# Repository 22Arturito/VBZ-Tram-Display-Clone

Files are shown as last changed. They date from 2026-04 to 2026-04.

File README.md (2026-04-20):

# VBZ Tram Display Clone

A homemade replica of the Zürich VBZ tram departure board. Shows real-time departure data for any tram, bus, or train station in Switzerland on three chained HUB75 LED matrix panels.






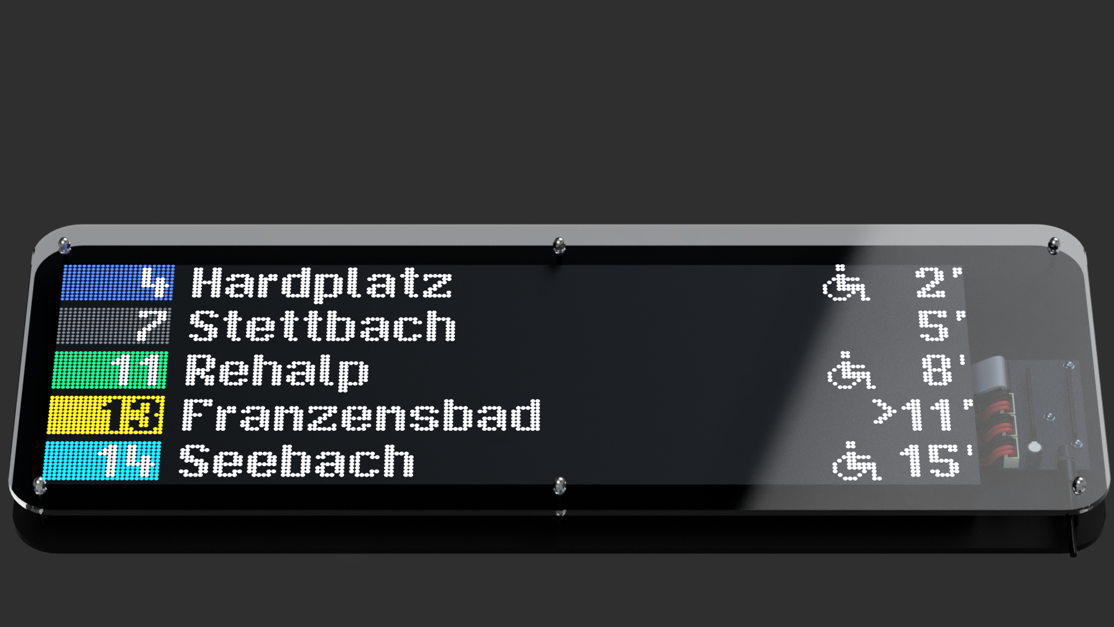
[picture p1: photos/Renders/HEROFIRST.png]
VBZ Tram Display


> Based on the original work by [sschueller](https://github.com/sschueller/vbz-fahrgastinformation).

---

## Table of Contents

- [Background](#background)
- [Features](#features)
- [Gallery](#gallery)
- [Build Your Own](#build-your-own)
- [Hardware](#hardware)
- [Wiring](#wiring)
- [Software Setup](#software-setup)
- [OTA Updates](#ota-updates)
- [Web Interface](#web-interface)
- [Physical Button](#physical-button)
- [Night Mode](#night-mode)
- [Troubleshooting](#troubleshooting)
- [Project Structure](#project-structure)
- [Contributors](#contributors)
- [Credits](#credits)

---

## Background

This project started with [sschueller's vbz-fahrgastinformation](https://github.com/sschueller/vbz-fahrgastinformation), a faithful recreation of the actual VBZ passenger information system, complete with the real font, real line colors, and real-time data from the Swiss open transport API. Pretty much everything technical in here traces back to his work — the firmware, the font and bitmap data, the HUB75 panel setup, the data pipeline. The things I added (web UI, clock screensaver with weather, night mode, OTA updates) are built on top of that. Big credit to him especially for the bitmap font work, which is the most distinctive visual part of the whole thing.

His original build used a single 64×128 panel. I switched to three chained 64×64 panels, which is close to what his newer products do and gives more flexibility when sourcing. The case design is heavily inspired by his finished [StationDisplay](https://www.stationdisplay.com) product. In many ways I wanted exactly what he sells, just as something I could build myself.

If you don't have the time or interest to build your own, I'd strongly recommend just buying from him directly at [stationdisplay.com](https://www.stationdisplay.com). It's an extraordinary Swiss-made product with proper support behind it.

This DIY version comes in at around CHF 80–120, which makes it accessible to a lot more people. That said, it is a DIY build. The finish, the support, and the overall quality of the bought version are on a different level. You get what you pay for.

A few things I contributed on top of his work:

- **Three 64×64 panels** chained to 192×64px total, instead of a single 64×128 panel
- **Custom PCB** for a clean, repeatable build
- **Laser-cut MDF and acrylic enclosure** closely inspired by his commercial StationDisplay
- **Web UI** for live configuration and station search
- **Clock screensaver** with date, live weather, UV index, and rain forecast
- **Night mode** with automatic scheduling and manual override
- **OTA firmware updates** over WiFi

---

## Features

- Live departure data from [opentransportdata.swiss](https://opentransportdata.swiss), falls back to scheduled if unavailable
- Two configurable stations, switchable via button or web interface
- Direction filter: both / outbound / inbound, persisted to flash
- VBZ tram line colors for all known Zürich lines
- Accessibility indicator for low-floor vehicles
- Live vs. scheduled marker, late departure indicator
- Night mode with amber colors and low brightness, auto-scheduled (22:00–06:00) with manual override
- Clock screensaver with date and live weather via [Open-Meteo](https://open-meteo.com), no API key needed
- Web configuration UI with live departure view and station search
- OTA firmware updates over WiFi

---

## Gallery

| | |
|---|---|
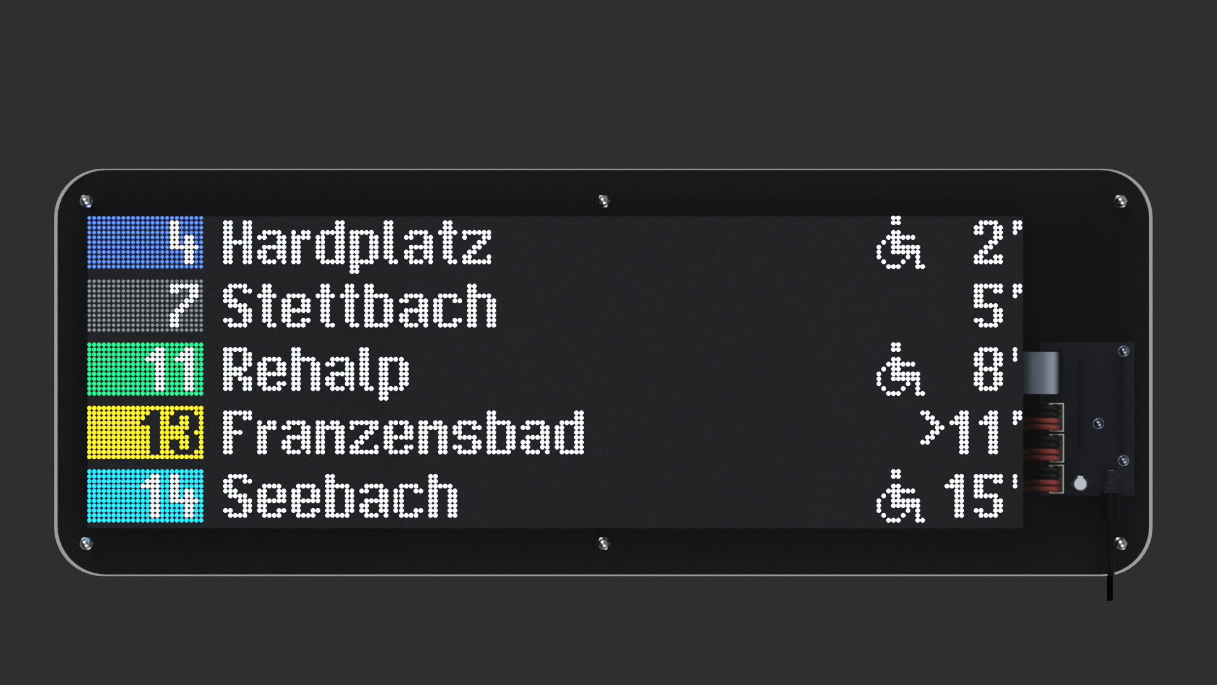
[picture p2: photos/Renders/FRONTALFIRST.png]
Front
| Hero |  |
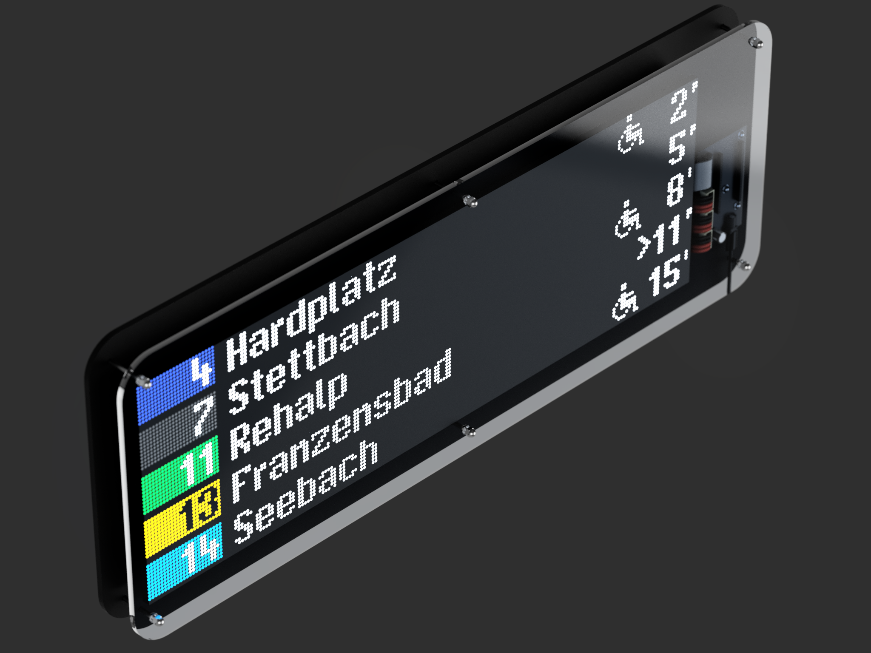
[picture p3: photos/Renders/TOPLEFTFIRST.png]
Top Left
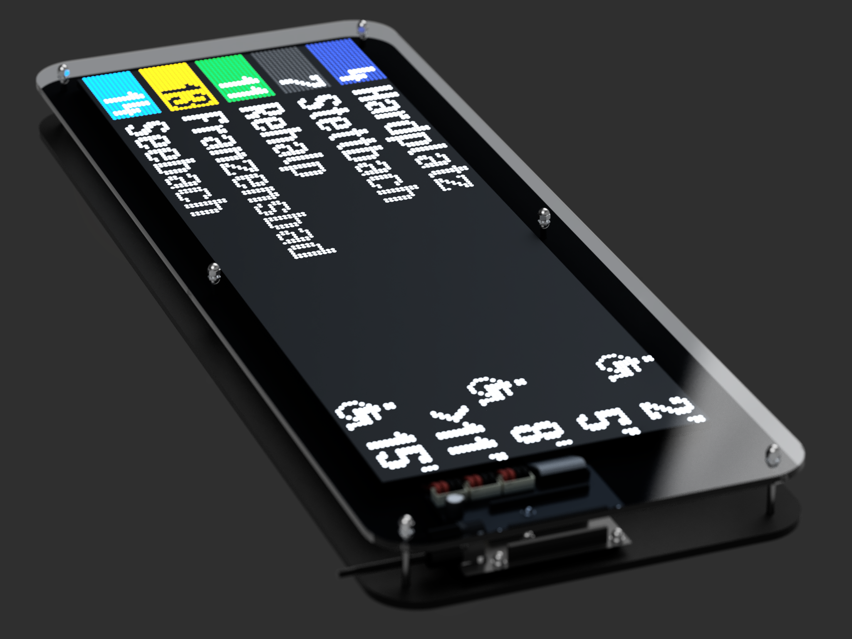
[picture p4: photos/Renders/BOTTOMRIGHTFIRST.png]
Bottom Right
|  |  |

---

## Build Your Own

Total cost is roughly **CHF 80–120** depending on where you source parts.

| Component | Source | Approx. Cost |
|---|---|---|
| 3× P3 64×64 HUB75E LED panels | AliExpress | CHF 45–60 |
| Freenove ESP32-S3 WROOM | AliExpress / Amazon | CHF 12–18 |
| Custom PCB (5 pcs min) | JLCPCB / PCBWay | CHF 8–12 |
| PCB components (caps, resistors, connectors) | LCSC / Mouser | CHF 5–10 |
| 5V 3A power supply | AliExpress | CHF 5–8 |
| 3× HUB75E ribbon cables (2×8 IDC) | AliExpress | CHF 4–6 |
| Acrylic sheet 600×200mm 5mm | Local laser shop | CHF 5–10 |
| MDF sheet 600×200mm 5mm | Local laser shop | CHF 3–5 |
| M4 hardware (bolts + nuts) | Hardware store | CHF 3–5 |

> Panels are the biggest variable in price and fluctuate on AliExpress. Search **"64x64 P3 HUB75E RGB LED matrix"**.

### Steps

1. **Order parts.** Use the BOM in `hardware/pcb/` for exact PCB components. Order panels, ESP32, and cables from AliExpress at the same time to save on shipping.

2. **Get the PCB made.** Upload the Gerber zip from `hardware/pcb/` to [JLCPCB](https://jlcpcb.com) or [PCBWay](https://pcbway.com). Standard 2-layer, 1.6mm, any colour. Minimum order is 5 pcs for ~$2.

3. **Laser-cut the frame.** Send the DXF files in `hardware/3d/` to a local laser cutting service or makerspace. 5mm MDF for the frame (paint it black), 5mm clear acrylic for the front panel.

4. **Solder the PCB.** Solder all SMD components first, then connectors. The schematic and assembly drawing are in `hardware/pcb/`.

5. **Assemble.** Chain the three LED panels together with ribbon cables. Connect power wires to each panel. Mount panels into the MDF frame using M4 bolts and nuts, then attach the acrylic front.

6. **Flash and configure.** Follow [Software Setup](#software-setup) below. First flash is via USB; all updates after that are OTA over WiFi.

---

## Hardware

| Component | Qty | Details |
|---|---|---|
| LED Matrix Panels | 3 | 64×64px P3 HUB75E, chained (192×64px total) |
| Microcontroller | 1 | Freenove ESP32-S3 WROOM (8MB Flash / 8MB PSRAM) |
| Custom PCB | 1 | See `hardware/pcb/` for schematics and BOM |
| Power Supply | 1 | 5V 3A DC barrel jack |
| HUB75E Ribbon Cables | 3 | 2×8 IDC, panel-to-panel and panel-to-PCB |
| JST Power Wires | 3 | Custom length, custom terminated |
| Acrylic sheet | 1 | 600×200mm, 5mm, laser-cut front panel |
| MDF sheet | 1 | 600×200mm, 5mm, laser-cut frame, painted black |
| M4 bolt 60mm | 6 | Frame assembly |
| M4 bolt 40mm | 12 | Frame assembly |
| M4 knurl nut | 9 | Frame assembly |
| M4 square nut | 12 | Frame assembly |

Laser-cut files are in `hardware/3d/`. PCB schematics and Gerber files are in `hardware/pcb/`.

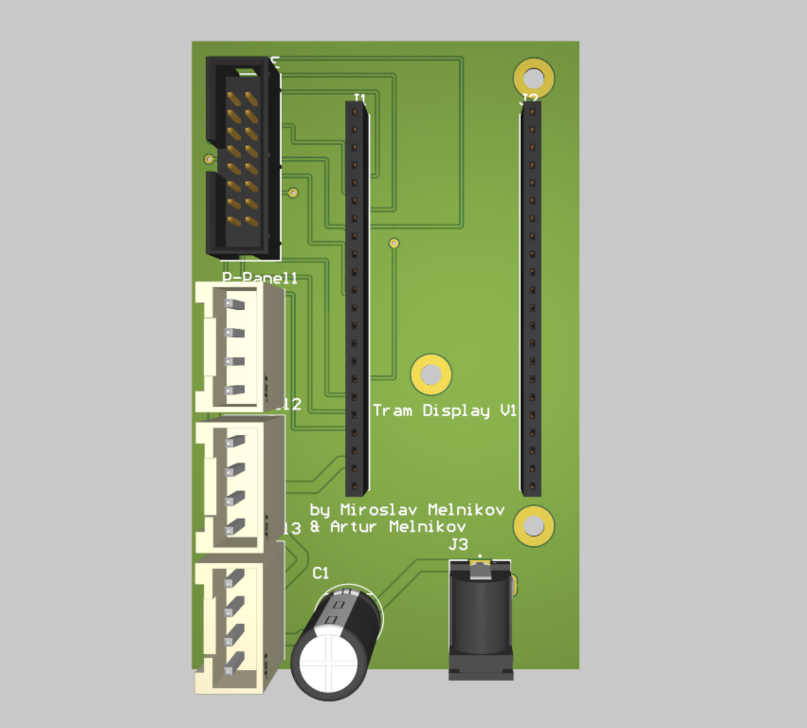
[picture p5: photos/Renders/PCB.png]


---

## Wiring

The custom PCB handles the connection between the ESP32-S3 and the HUB75E panels.

| HUB75E Pin | ESP32-S3 GPIO |
|---|---|
| R1 | 4 |
| G1 | 5 |
| B1 | 6 |
| R2 | 7 |
| G2 | 15 |
| B2 | 16 |
| A | 17 |
| B | 18 |
| C | 8 |
| D | 14 |
| E | 10 |
| LAT | 11 |
| OE | 12 |
| CLK | 13 |

> Double-check against your `Config.h` as pin assignments can vary.

---

## Software Setup

### 1. Configure `firmware/include/Config.h`

Copy the template and fill in your details:

```bash
cp firmware/include/Config.h.dist firmware/include/Config.h
```

```cpp
#define OPEN_DATA_API_KEY "your_key_here"  // from opentransportdata.swiss
#define WEATHER_LAT "47.37"                // your latitude
#define WEATHER_LON "8.54"                 // your longitude
#define BRIGHTNESS_FIXED 80               // 0–255, or -1 for ambient sensor
```

Get a free API key at [opentransportdata.swiss](https://opentransportdata.swiss).
Find station BPUIC IDs in the xlsx at [bav_liste](https://opentransportdata.swiss/de/dataset/bav_liste).

### 2. Flash via USB

Open the `firmware/` folder in PlatformIO and flash:

```bash
pio run -e freenove_esp32_s3_wroom -t upload
```

### 3. Connect to WiFi

On first boot the display shows **"connect to: vbz-anzeige"**. Connect to that network (password: `123456`), open a browser and the captive portal opens automatically. Enter your home WiFi credentials and save.

### 4. Configure stations

After connecting, the display shows its IP. Open `http://<IP>/config` to set your stations, night hours, and brightness.

---

## OTA Updates

After the first USB flash, all future updates can be done wirelessly.

Set the device IP in `firmware/platformio.ini`:

```ini
upload_port = 192.168.1.xx
```

Then upload:

```bash
pio run -e ota -t upload
```

OTA password: `vbz1234` (configurable in `main.cpp`).

---

## Web Interface

Open `http://<IP>/config` in any browser on the same network.

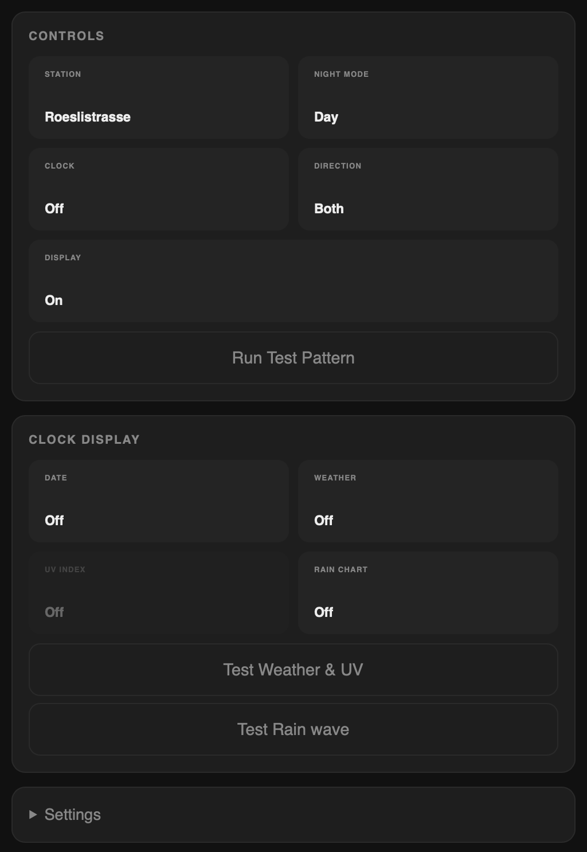
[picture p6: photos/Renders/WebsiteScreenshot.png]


| Button | Action |
|---|---|
| Switch Station | Toggle between Station 1 and Station 2 |
| Switch to Night / Day | Toggle night mode manually |
| Dir: Both / H / R | Cycle direction filter |
| Turn Off / On | Toggle display on/off |
| Clock: Off / On | Toggle clock screensaver |
| Test Display | Flash red/green/blue/white to verify panels |

Station search lets you look up a stop by name and fills the BPUIC ID automatically.

---

## Physical Button

| Press | Action |
|---|---|
| Single press | Switch between Station 1 and Station 2 |
| Double press | Toggle night mode |
| Long press (>800ms) | Toggle display off/on |

---

## Night Mode

Activates automatically between configured hours (default 22:00–06:00). All colors switch to amber and brightness drops to ~10%. Can be overridden manually via button or web interface and the override clears at the next scheduled boundary.

---

## Troubleshooting

**Display shows garbage / random pixels**
Check ribbon cable orientation. HUB75E cables are not keyed, try flipping the connector on the first panel.

**Only the first panel lights up**
The chain order matters. Panel 1 connects to the PCB, panel 2 connects to panel 1's output, panel 3 to panel 2's output.

**No departures shown, just dashes**
Your API key is missing or wrong. Double-check `Config.h` and make sure you have a valid key from [opentransportdata.swiss](https://opentransportdata.swiss).

**OTA upload fails**
Make sure the device is on the same network and the IP in `platformio.ini` is correct. The OTA password is `vbz1234`.

**Display flickers or shows noise**
Lower `BRIGHTNESS_FIXED` in `Config.h`. Some panels need `latch_blanking` tuned, see the comments in `Display.cpp`.

**WiFi captive portal doesn't open**
Navigate manually to `192.168.4.1` in your browser after connecting to the `vbz-anzeige` hotspot.

---

## Project Structure

```
firmware/           ESP32 PlatformIO project
hardware/
  pcb/              Schematic, Gerber files, BOM
  3d/               Laser-cut DXF files for MDF frame and acrylic panel
photos/             Build photos and renders
generate_texture.py Generates a P3 LED texture for renders
```

---

## Contributors

**Artur Melnikov** — firmware, PCB, enclosure design, renders

**Miroslav Melnikov** — recreated the LED display panels in CAD, display testing, and a genuine interest in the project that kept it moving

**Bhavya Sharma** — helped with soldering and assembling the physical display

---

## Credits

Built on top of [sschueller's vbz-fahrgastinformation](https://github.com/sschueller/vbz-fahrgastinformation), used under MIT license. The original concept, font, and data pipeline approach all originate from his work. This project wouldn't exist without it.

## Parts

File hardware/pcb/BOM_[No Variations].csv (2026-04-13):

Name | Description | Designator | Part Number | Price | Qty
EEUTA1A102 | Aluminum Electrolytic Capacitors (Radial Lead Type) AEC-Q200 Qualified 1000uF ±20% 10V | C1 | Panasonic EEUTA1A102 |  | 1
61201621621 | WR-BHD Straight Male, Box Header, Through Hole, 2 Rows, 16 Contacts, 2.54mm Pitch | HUB75E | Wurth Elektronik 61201621621 | 0.60978 | 1
61302211821 | Btb Conn, Rcpt, 22Pos, 1Row, 2.54Mm Rohs Compliant: Yes | J1, J2 | Wurth Elektronik 61302211821, | 9.58055 | 2
PJ-102A | PJ-102A 2.0 x 6.5 mm, 2.5 A, Horizontal, Through Hole, Tapered Pins, Dc Power Jack Connector | J3 | Same Sky PJ-102A | 0.3306 | 1
BH4P-VH-1(LF)(SN) | VH Series 4 Position 3.96 mm Pitch Through Hole Shrouded Header | P_Panel3, P-Panel1, P-Panel2 | JST BH4P-VH-1(LF)(SN), | 0.7965 | 3

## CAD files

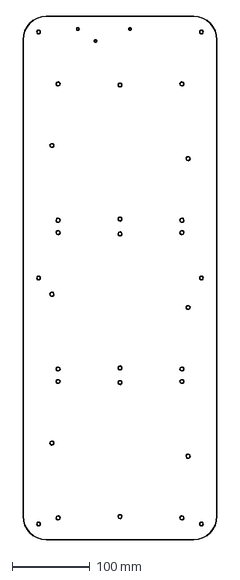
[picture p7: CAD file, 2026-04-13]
hardware/3d/Lasercutter Files/MDF BasePlate .dxf
250.0 x 675.0 mm

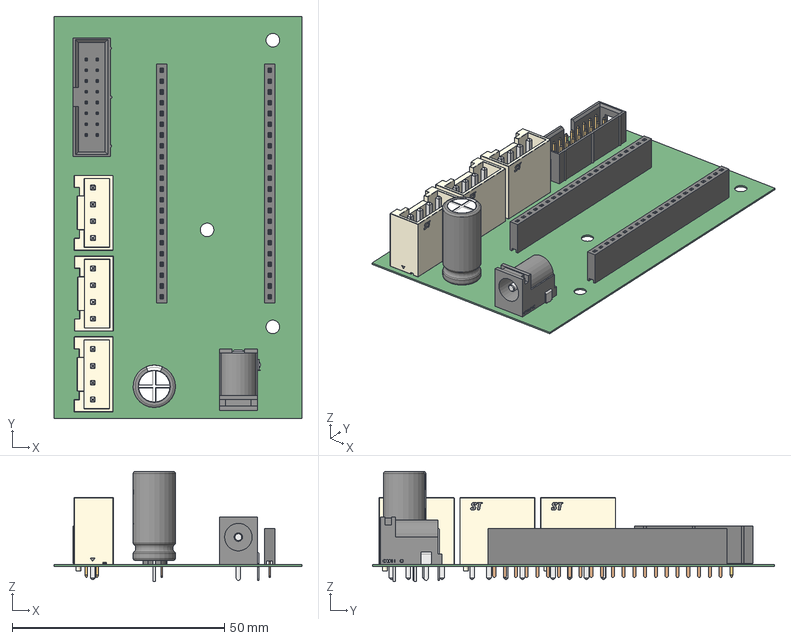
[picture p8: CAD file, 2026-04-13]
hardware/pcb/STEP_[No Variations] for PCB1.PcbDoc.step
58.4 x 94.7 x 26.0 mm
Pins x 3
Pin1_Triangle x 3
JST x 3
logo x 2
6130xx11821_PIN x 44
6120xx21621_PIN x 16
marking
bottom
polarity marking
top
terminal

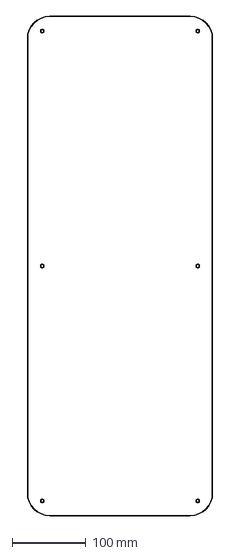
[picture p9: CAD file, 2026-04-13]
hardware/3d/Lasercutter Files/AcrylicFrontPlate.dxf
250.0 x 675.0 mm

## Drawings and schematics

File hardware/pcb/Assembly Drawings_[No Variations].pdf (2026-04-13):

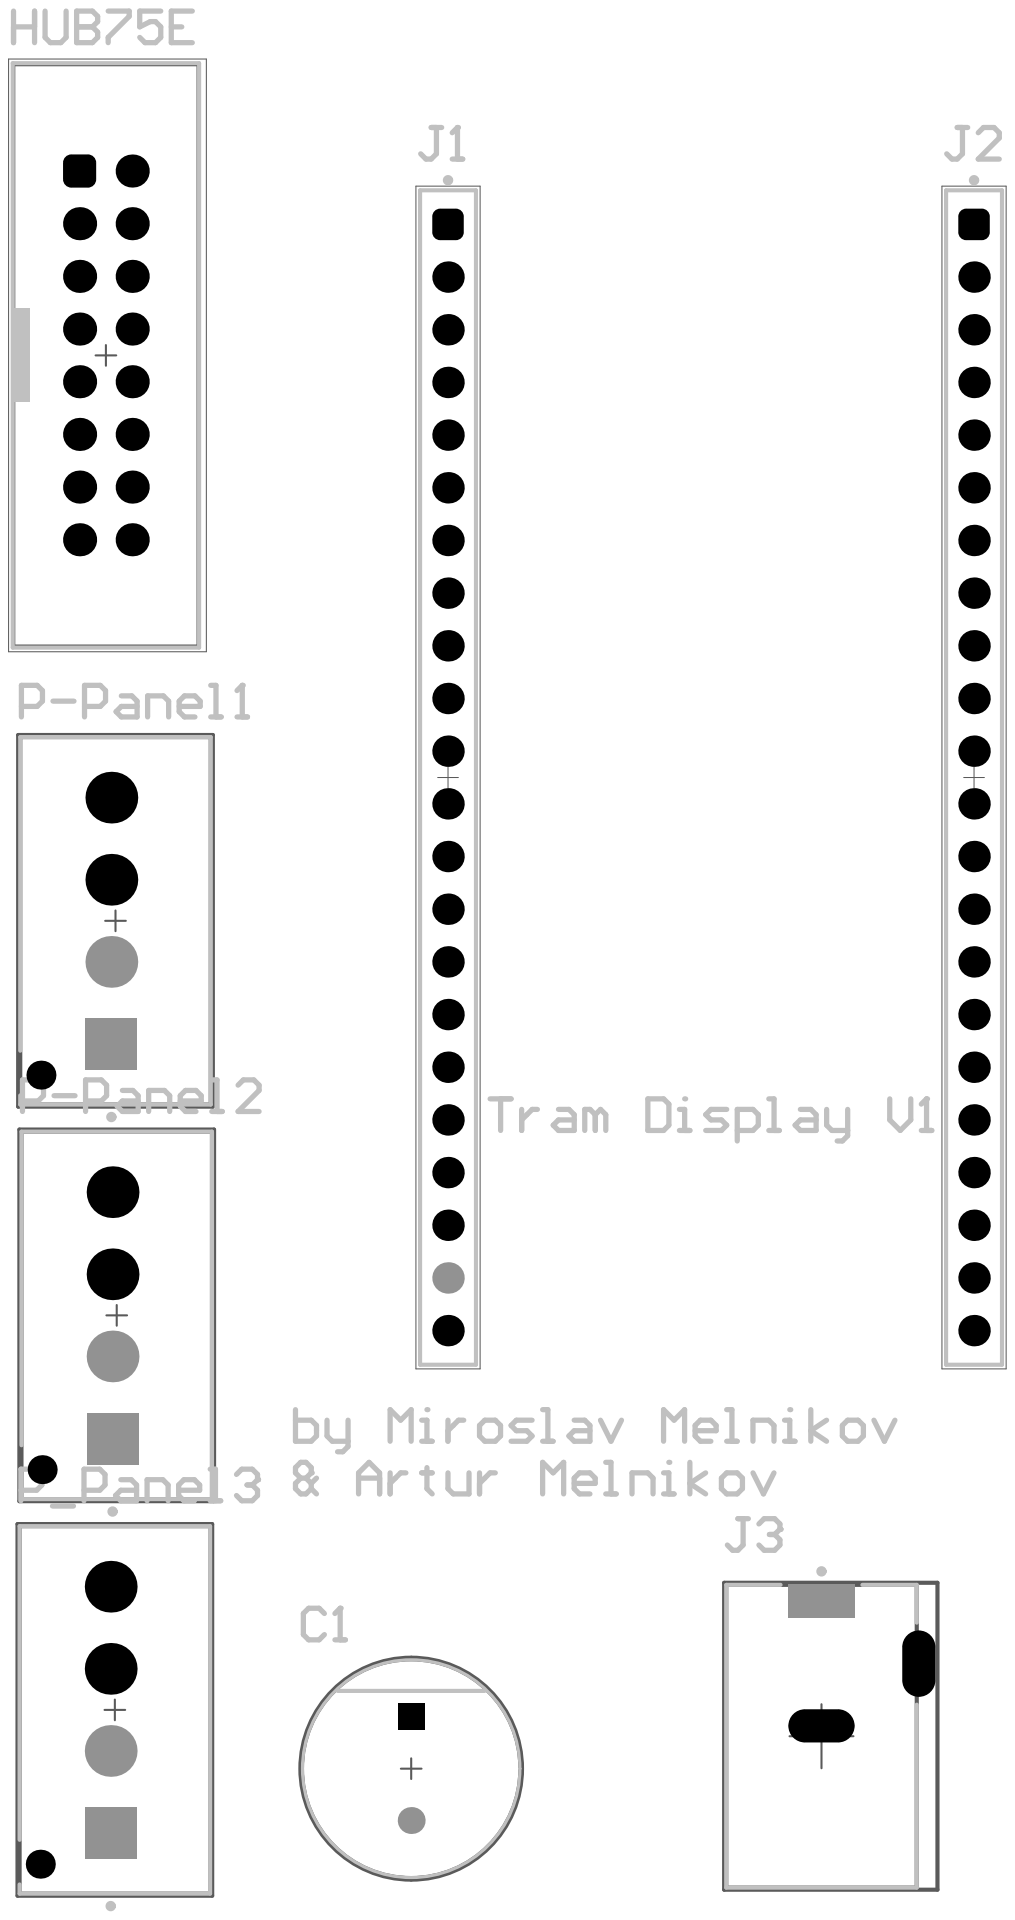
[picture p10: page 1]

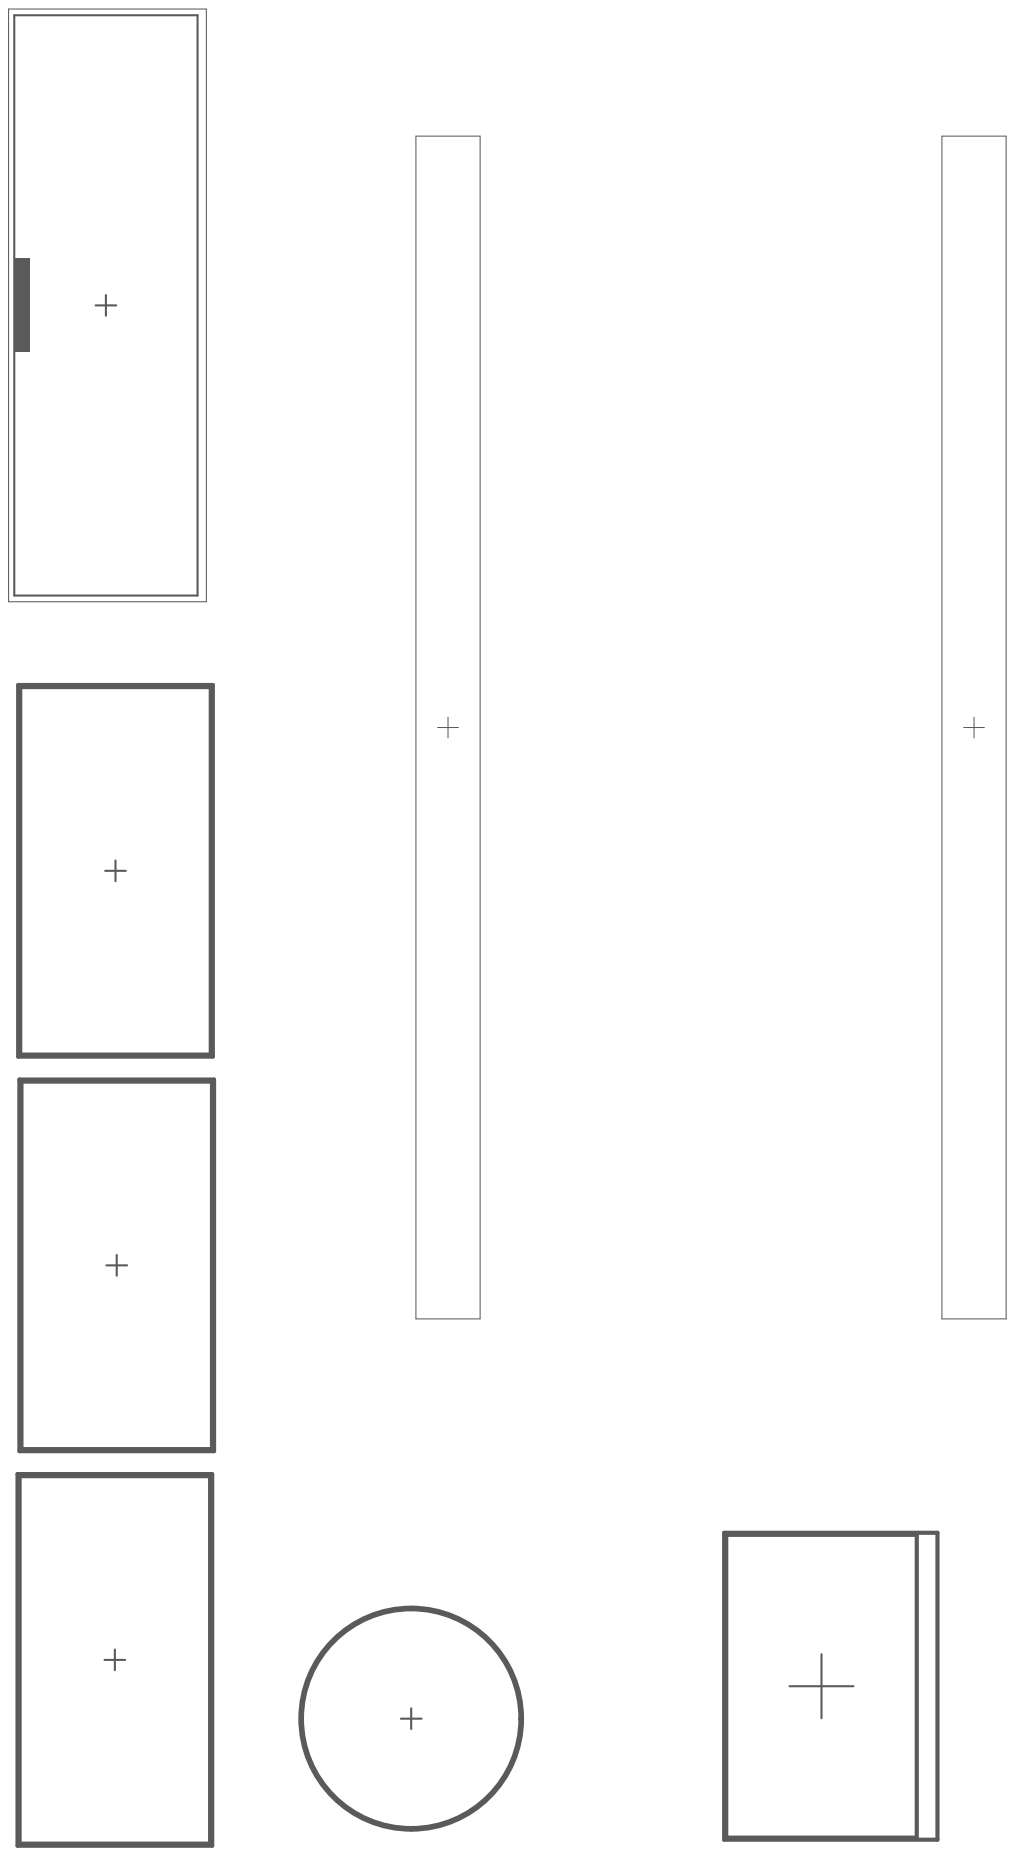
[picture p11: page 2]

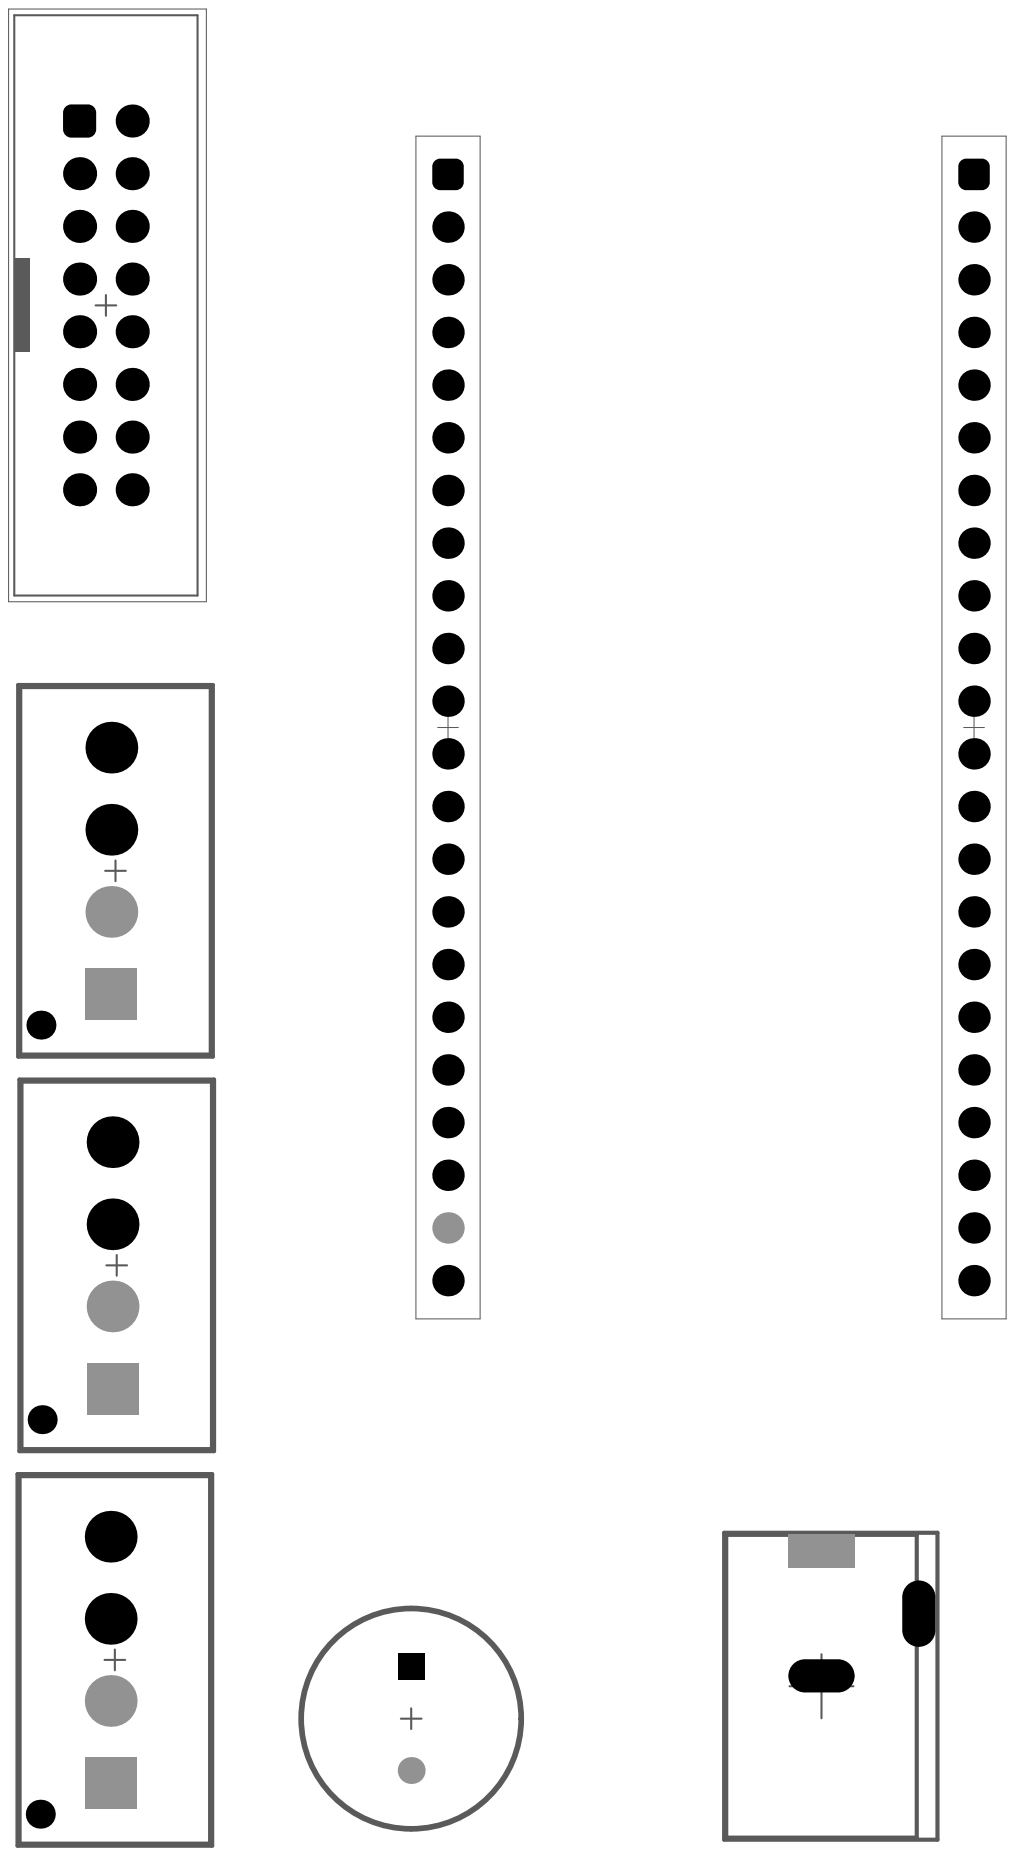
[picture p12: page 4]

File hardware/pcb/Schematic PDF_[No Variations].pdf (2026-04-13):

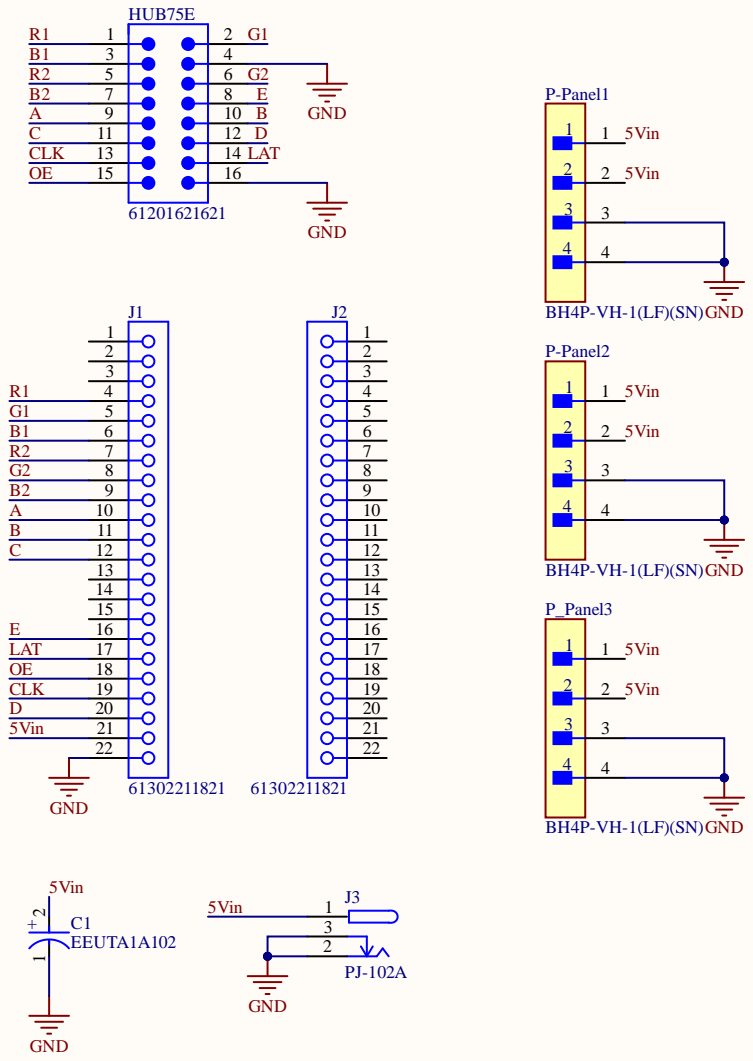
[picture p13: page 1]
Date:; Sheet of; File:; Sheet1.SchDoc; Drawn By:

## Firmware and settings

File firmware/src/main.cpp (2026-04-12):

#include <Config.h>
#include <Arduino.h>
#include <Wire.h>
#include <SPI.h>
#include <WiFi.h>
#include <AutoConnect.h>
#include <WebServer.h>
#include <NTPClient.h>
#include <Preferences.h>
#include <ArduinoOTA.h>
#include <ESPmDNS.h>

#include <Display.h>
#include <OpenTransportDataSwiss.h>

// --- DST HELPERS (Central Europe: CET=UTC+1, CEST=UTC+2) ---

static int _dow(int y, int m, int d) {
    static const int t[] = {0,3,2,5,0,3,5,1,4,6,2,4};
    if (m < 3) y--;
    return (y + y/4 - y/100 + y/400 + t[m-1] + d) % 7;
}

static int _lastSun(int y, int m) {
    int days = (m==1||m==3||m==5||m==7||m==8||m==10||m==12) ? 31 :
               (m==4||m==6||m==9||m==11) ? 30 :
               (y%4==0 && (y%100!=0 || y%400==0)) ? 29 : 28;
    return days - _dow(y, m, days);
}

static bool _isCEST(int y, int m, int d, int h) {
    if (m < 3 || m > 10) return false;
    if (m > 3 && m < 10) return true;
    int b = _lastSun(y, m);
    if (m == 3) return (d > b || (d == b && h >= 1));
    return (d < b || (d == b && h < 1));
}

// --- GLOBALS ---

int timeOffset = 3600;
const char* timeServer = TIME_SERVER;
const int BUTTON_PIN = 0;

// Runtime config (loaded from NVS on boot)
Preferences prefs;
String station1Id    = "8591324";
String station1Name  = "Roeslistrasse";
String station2Id    = "8591237";
String station2Name  = "Kronenstrasse";
int    nightStart    = 22;
int    nightEnd      = 6;
int    cfgBrightness = -1;  // -1 = auto/sensor
String cfgDirection  = "A"; // A=both, H=outbound, R=inbound

bool showRoesli    = true;
bool nightMode     = false;
bool displayOff    = false;
bool clockMode     = false;
bool manualOverride = false;
bool clkShowDate   = true;
bool clkShowWx     = true;
bool clkShowUv     = true;
bool clkShowRain   = true;
int  lastAutoHour   = -1;
int  sensorValue;
unsigned long lastTick = 0;

// Weather (written by core 0 task, read by core 1 loop)
volatile float wxTemp      = 0.0f;
volatile bool  wxValid     = false;
volatile char  wxDescBuf[16] = "";
volatile bool  wxRainToday = false;
volatile int   wxRainProb  = 0;
volatile float wxUvMax     = -1.0f;
volatile float wxHourlyRain[24] = {};

// Departure fetch task
SemaphoreHandle_t deptMutex  = NULL;
TaskHandle_t      deptTaskHandle = NULL;
volatile bool     newDeptData   = false;
volatile int      deptLastCode  = 0;
char              deptErrBuf[64] = "";

// Button state machine
enum BtnState { BTN_IDLE, BTN_PRESSED, BTN_WAIT_DOUBLE };
BtnState btnState = BTN_IDLE;
unsigned long btnPressStart  = 0;
unsigned long btnReleaseTime = 0;
bool btnPrev = false;

const unsigned long LONG_PRESS_MS   = 800;
const unsigned long DOUBLE_PRESS_MS = 400;

OpenTransportDataSwiss* api = nullptr;

Display display;
WebServer Server;
AutoConnect Portal(Server);
AutoConnectConfig Config;
WiFiUDP ntpUDP;
NTPClient timeClient(ntpUDP, timeServer, timeOffset, 60000);

// --- DST: compute correct UTC offset for current NTP time ---

int computeTimeOffset() {
    unsigned long utc = (unsigned long)timeClient.getEpochTime() - (unsigned long)timeOffset;
    int h    = (utc / 3600) % 24;
    long days = utc / 86400;
    int y = 1970;
    while (true) {
        int diy = (y%4==0 && (y%100!=0 || y%400==0)) ? 366 : 365;
        if (days < diy) break;
        days -= diy; y++;
    }
    static const int md[12] = {31,28,31,30,31,30,31,31,30,31,30,31};
    bool leap = (y%4==0 && (y%100!=0 || y%400==0));
    int m = 0;
    for (; m < 12; m++) {
        int dim = md[m] + (m==1 && leap ? 1 : 0);
        if (days < dim) break;
        days -= dim;
    }
    return _isCEST(y, m+1, (int)days+1, h) ? 7200 : 3600;
}

// --- NVS CONFIG ---

void loadConfig() {
    prefs.begin("vbz", true);
    station1Id    = prefs.getString("s1id",    "8591324");
    station1Name  = prefs.getString("s1name",  "Roeslistrasse");
    station2Id    = prefs.getString("s2id",    "8591237");
    station2Name  = prefs.getString("s2name",  "Kronenstrasse");
    nightStart    = prefs.getInt("ns",    22);
    nightEnd      = prefs.getInt("ne",     6);
    cfgBrightness = prefs.getInt("bright", -1);
    cfgDirection  = prefs.getString("dir", "A");
    clkShowDate   = prefs.getBool("clkdate", true);
    clkShowWx     = prefs.getBool("clkwx",   true);
    clkShowUv     = prefs.getBool("clkuv",   true);
    clkShowRain   = prefs.getBool("clkrain", true);
    prefs.end();
}

void saveConfig() {
    prefs.begin("vbz", false);
    prefs.putString("s1id",    station1Id);
    prefs.putString("s1name",  station1Name);
    prefs.putString("s2id",    station2Id);
    prefs.putString("s2name",  station2Name);
    prefs.putInt("ns",    nightStart);
    prefs.putInt("ne",    nightEnd);
    prefs.putInt("bright", cfgBrightness);
    prefs.putString("dir", cfgDirection);
    prefs.putBool("clkdate", clkShowDate);
    prefs.putBool("clkwx",   clkShowWx);
    prefs.putBool("clkuv",   clkShowUv);
    prefs.putBool("clkrain", clkShowRain);
    prefs.end();
}

// --- WEATHER ---

static String wxCodeStr(int code) {
    if (code == 0)   return "Clear";
    if (code <= 3)   return "Cloudy";
    if (code <= 48)  return "Fog";
    if (code <= 67)  return "Rain";
    if (code <= 77)  return "Snow";
    if (code <= 82)  return "Showers";
    return                  "Storm";
}

// Single HTTP task — weather + departures run sequentially, no mutex needed for HTTP
void httpTask(void*) {
    unsigned long lastWeatherMs = 0;
    for (;;) {
        if (WiFi.status() == WL_CONNECTED) {

            // --- Weather (every 10 min) ---
            unsigned long now = millis();
            if (!wxValid || (now - lastWeatherMs >= 10UL * 60 * 1000)) {
                WiFiClientSecure *wc = new WiFiClientSecure;
                if (wc) {
                    wc->setInsecure();
                    HTTPClient wh;
                    wh.setTimeout(8000);
                    // --- Single call: current conditions + daily summary + hourly precipitation ---
                    String wurl = String("https://api.open-meteo.com/v1/forecast"
                        "?latitude=" WEATHER_LAT "&longitude=" WEATHER_LON
                        "&current=temperature_2m,weather_code"
                        "&hourly=precipitation"
                        "&daily=precipitation_probability_max,uv_index_max"
                        "&forecast_days=1"
                        "&timezone=auto");
                    bool gotWeather = false;
                    if (wh.begin(*wc, wurl) && wh.GET() == 200) {
                        StaticJsonDocument<384> wfilter;
                        wfilter["current"]["temperature_2m"] = true;
                        wfilter["current"]["weather_code"]   = true;
                        wfilter["hourly"]["precipitation"][0] = true;
                        wfilter["daily"]["precipitation_probability_max"][0] = true;
                        wfilter["daily"]["uv_index_max"][0]  = true;
                        StaticJsonDocument<1024> wdoc;
                        String body = wh.getString();
                        if (deserializeJson(wdoc, body,
                                DeserializationOption::Filter(wfilter)) == DeserializationError::Ok) {
                            wxTemp = wdoc["current"]["temperature_2m"].as<float>();
                            String d = wxCodeStr(wdoc["current"]["weather_code"].as<int>());
                            strncpy((char*)wxDescBuf, d.c_str(), sizeof(wxDescBuf) - 1);
                            ((char*)wxDescBuf)[sizeof(wxDescBuf) - 1] = '\0';
                            int rainProb = wdoc["daily"]["precipitation_probability_max"][0] | 0;
                            wxRainToday = (rainProb >= 40);
                            wxRainProb  = rainProb;
                            wxUvMax     = wdoc["daily"]["uv_index_max"][0] | -1.0f;
                            JsonArray hp = wdoc["hourly"]["precipitation"];
                            for (int i = 0; i < 24 && i < (int)hp.size(); i++)
                                wxHourlyRain[i] = hp[i].as<float>();
                            gotWeather = true;
                            Serial.printf("Weather: %.1fC %s rain=%d%% uv=%.1f hp[0]=%.2f hp[12]=%.2f\n",
                                wxTemp, d.c_str(), rainProb, (float)wxUvMax,
                                (float)wxHourlyRain[0], (float)wxHourlyRain[12]);
                        } else Serial.println("Weather: parse error");
                    } else Serial.printf("Weather: request failed, heap=%d\n", ESP.getMaxAllocHeap());
                    wh.end();

                    if (gotWeather) wxValid = true;
                    delete wc;
                } else Serial.printf("Weather: alloc failed, heap=%d\n", ESP.getMaxAllocHeap());
                lastWeatherMs = millis();
            }

            // --- Departures ---
            // Free old api FIRST to maximise contiguous DRAM available for TLS
            xSemaphoreTake(deptMutex, portMAX_DELAY);
            if (api != nullptr) { api->~OpenTransportDataSwiss(); free(api); api = nullptr; }
            xSemaphoreGive(deptMutex);

            // Allocate api object in PSRAM so the 4KB JSON doc doesn't eat DRAM needed by TLS
            String stationId = showRoesli ? station1Id : station2Id;
            void* apiBuf = heap_caps_malloc(sizeof(OpenTransportDataSwiss), MALLOC_CAP_SPIRAM | MALLOC_CAP_8BIT);
            if (!apiBuf) apiBuf = malloc(sizeof(OpenTransportDataSwiss));
            Serial.printf("API buf: %p  dram_free=%d\n", apiBuf, (int)ESP.getMaxAllocHeap());
            if (!apiBuf) { ulTaskNotifyTake(pdTRUE, pdMS_TO_TICKS(32000)); continue; }
            OpenTransportDataSwiss* newApi = new(apiBuf) OpenTransportDataSwiss(
                stationId, cfgDirection, OPEN_DATA_URL, OPEN_DATA_API_KEY, OPEN_DATA_RESULTS);
            int code = newApi->getWebData(timeClient);

            char errBuf[64] = "";
            if (code != 0) strncpy(errBuf, newApi->httpLastError.c_str(), sizeof(errBuf) - 1);

            xSemaphoreTake(deptMutex, portMAX_DELAY);
            api         = newApi;
            deptLastCode = code;
            strncpy(deptErrBuf, errBuf, sizeof(deptErrBuf) - 1);
            newDeptData = true;
            xSemaphoreGive(deptMutex);

            if (code == 0) Serial.println("Dept: OK");
            else Serial.printf("Dept: error %d %s\n", code, errBuf);
        }
        // Wait 32s, or wake immediately on station/direction/config change
        ulTaskNotifyTake(pdTRUE, pdMS_TO_TICKS(32000));
    }
}

// --- CLOCK HELPERS ---

String clockDate() {
    String fd = timeClient.getFormattedDate(); // "YYYY-MM-DDTHH:MM:SSZ"
    return fd.substring(8, 10) + "." + fd.substring(5, 7) + "." + fd.substring(0, 4);
}

void showClockNow() {
    String wx = "";
    if (!wxValid)
        wx = "heap:" + String(ESP.getMaxAllocHeap() / 1024) + "K";
    else if (clkShowWx)
        wx = String((int)round(wxTemp)) + "C  " + String((const char*)wxDescBuf);

    float uvToShow = (clkShowWx && clkShowUv) ? (float)wxUvMax : -1.0f;

    float hourlyRainCopy[24];
    const float* rainPtr = nullptr;
    if (wxValid && clkShowRain) {
        for (int i = 0; i < 24; i++) hourlyRainCopy[i] = wxHourlyRain[i];
        rainPtr = hourlyRainCopy;
    }

    display.showClock(timeClient.getHours(), timeClient.getMinutes(),
                      timeClient.getSeconds(), clkShowDate ? clockDate() : "", wx,
                      wxRainToday, uvToShow, rainPtr);
}

// --- RENDER HELPER ---

void reRender() {
    if (displayOff) {
        display.turnOff();
    } else if (clockMode) {
        showClockNow();
    } else if (xSemaphoreTake(deptMutex, pdMS_TO_TICKS(500)) == pdTRUE) {
        if (api != nullptr) {
            if (deptLastCode == 0) display.printLines(api->doc.as<JsonArray>());
            else display.printError("API Error: " + String(deptLastCode) + "\n" + String(deptErrBuf) + "\nheap:" + String(ESP.getMaxAllocHeap() / 1024) + "K");
        }
        xSemaphoreGive(deptMutex);
    }
}

// --- XML HELPER ---

static String _xv(const String& doc, const char* open, const char* close) {
    int s = doc.indexOf(open);
    if (s < 0) return "";
    s += strlen(open);
    int e = doc.indexOf(close, s);
    if (e < 0) return "";
    return doc.substring(s, e);
}

// --- STATUS ENDPOINT ---

void handleStatus() {
    String s = "wxValid: " + String(wxValid ? "true" : "false") + "\n";
    s += "temp:    " + String(wxTemp) + " C\n";
    s += "desc:    " + String((const char*)wxDescBuf) + "\n";
    s += "uvMax:   " + String(wxUvMax) + "\n";
    s += "rainToday: " + String(wxRainToday ? "true" : "false") + " (" + String(wxRainProb) + "%)\n";
    s += "\nhourly precipitation (mm/h):\n";
    for (int i = 0; i < 24; i++) {
        char line[32];
        snprintf(line, sizeof(line), "  %02d:00  %.2f\n", i, (float)wxHourlyRain[i]);
        s += line;
    }
    Server.send(200, "text/plain", s);
}

// --- DEPARTURES ENDPOINT ---

void handleDepartures() {
    if (xSemaphoreTake(deptMutex, pdMS_TO_TICKS(500)) != pdTRUE) {
        Server.send(200, "application/json", "[]"); return;
    }
    if (api == nullptr) { xSemaphoreGive(deptMutex); Server.send(200, "application/json", "[]"); return; }
    String json;
    serializeJson(api->doc, json);
    xSemaphoreGive(deptMutex);
    Server.send(200, "application/json", json);
}

// --- STATION SEARCH ENDPOINT ---

void handleSearch() {
    String query = Server.arg("q");
    if (!query.length()) { Server.send(200, "application/json", "[]"); return; }

    WiFiClientSecure* client = new WiFiClientSecure;
    if (!client) { Server.send(200, "application/json", "[]"); return; }
    client->setInsecure();
    HTTPClient https;
    https.setTimeout(8000);

    String auth = String(OPEN_DATA_API_KEY);
    if (!auth.startsWith("Bearer ")) auth = "Bearer " + auth;

    String ts = timeClient.getFormattedDate();
    String body =
        "<?xml version=\"1.0\" encoding=\"UTF-8\"?>"
        "<OJP xmlns=\"http://www.vdv.de/ojp\" xmlns:siri=\"http://www.siri.org.uk/siri\" version=\"2.0\">"
        "<OJPRequest><siri:ServiceRequest>"
        "<siri:ServiceRequestContext><siri:Language>de</siri:Language></siri:ServiceRequestContext>"
        "<siri:RequestTimestamp>" + ts + "</siri:RequestTimestamp>"
        "<siri:RequestorRef>tramdisplay</siri:RequestorRef>"
        "<OJPLocationInformationRequest>"
        "<siri:RequestTimestamp>" + ts + "</siri:RequestTimestamp>"
        "<siri:MessageIdentifier>LIR-1</siri:MessageIdentifier>"
        "<InitialInput><LocationName>" + query + "</LocationName></InitialInput>"
        "<Restrictions><Type>stop</Type><NumberOfResults>6</NumberOfResults></Restrictions>"
        "</OJPLocationInformationRequest>"
        "</siri:ServiceRequest></OJPRequest></OJP>";

    String json = "[]";
    if (https.begin(*client, OPEN_DATA_URL)) {
        https.addHeader("Authorization", auth);
        https.addHeader("Content-Type", "application/xml");
        if (https.POST(body) == 200) {
            String xml = https.getString();
            json = "[";
            bool first = true;
            while (true) {
                int end = xml.indexOf("</ojp:Location>");
                if (end < 0) end = xml.indexOf("</Location>");
                if (end < 0) break;
                String block = xml.substring(0, end);
                xml = xml.substring(end + 15);

                String ref = _xv(block, "<siri:StopPointRef>", "</siri:StopPointRef>");
                if (!ref.length()) ref = _xv(block, "<StopPointRef>", "</StopPointRef>");
                String name = _xv(block, "<ojp:Text>", "</ojp:Text>");
                if (!name.length()) name = _xv(block, "<Text>", "</Text>");
                name.replace("\"", "\\\"");

                if (ref.length() && name.length()) {
                    if (!first) json += ",";
                    json += "{\"id\":\"" + ref + "\",\"name\":\"" + name + "\"}";
                    first = false;
                }
            }
            json += "]";
        }
        https.end();
    }
    delete client;
    Server.send(200, "application/json", json);
}

// --- WEB CONFIG HANDLERS ---
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
void loop() {
    ArduinoOTA.handle();
    Portal.handleClient();
    timeClient.update();

    // --- 1. KNOPF-ERKENNUNG ---
    bool btnCurrent  = (digitalRead(BUTTON_PIN) == LOW);
    bool btnPressed  = (btnCurrent && !btnPrev);
    bool btnReleased = (!btnCurrent && btnPrev);
    btnPrev = btnCurrent;

    switch (btnState) {
        case BTN_IDLE:
            if (btnPressed) {
                btnPressStart = millis();
                btnState = BTN_PRESSED;
            }
            break;

        case BTN_PRESSED:
            if (btnReleased) {
                if (millis() - btnPressStart >= LONG_PRESS_MS) {
                    // Long press -> toggle display off/on
                    displayOff = !displayOff;
                    reRender();
                    Serial.println(displayOff ? "Display OFF" : "Display ON");
                    btnState = BTN_IDLE;
                } else {
                    btnReleaseTime = millis();
                    btnState = BTN_WAIT_DOUBLE;
                }
            }
            break;

        case BTN_WAIT_DOUBLE:
            if (btnPressed) {
                // Double press -> toggle night mode (manual override until next boundary)
                manualOverride = true;
                nightMode = !nightMode;
                display.setNightMode(nightMode);
                reRender();
                Serial.println(nightMode ? "Night mode ON (manual)" : "Night mode OFF (manual)");
                btnState = BTN_IDLE;
            } else if (millis() - btnReleaseTime >= DOUBLE_PRESS_MS) {
                // Single press -> switch station
                showRoesli = !showRoesli;
                display.connectingMsg();
                if (deptTaskHandle) xTaskNotifyGive(deptTaskHandle);
                Serial.println("Switch -> " + (showRoesli ? station1Name : station2Name));
                btnState = BTN_IDLE;
            }
            break;
    }

    // --- 2. DIE SEKUNDEN-SCHLEIFE ---
    if (millis() - lastTick >= 1000 || lastTick == 0) {
        lastTick = millis();

        // --- AUTO NIGHT MODE ---
        int currentHour = timeClient.getHours();
        if (currentHour != lastAutoHour) {
            lastAutoHour = currentHour;

            // Update DST offset on every hour change
            int newOffset = computeTimeOffset();
            if (newOffset != timeOffset) {
                timeOffset = newOffset;
                timeClient.setTimeOffset(timeOffset);
                Serial.printf("DST changed: %d (%s)\n", timeOffset, timeOffset == 7200 ? "CEST" : "CET");
            }

            // At night mode boundaries, clear manual override
            if (currentHour == nightStart || currentHour == nightEnd) {
                manualOverride = false;
                Serial.println("Auto night boundary, manual override cleared");
            }
        }

        if (!manualOverride) {
            bool schedNight = (nightStart != nightEnd) && (
                nightStart > nightEnd
                    ? (currentHour >= nightStart || currentHour < nightEnd)
                    : (currentHour >= nightStart && currentHour < nightEnd)
            );
            if (schedNight != nightMode) {
                nightMode = schedNight;
                display.setNightMode(nightMode);
                reRender();
                Serial.println(nightMode ? "Auto: Night mode ON" : "Auto: Night mode OFF");
            }
        }

        // --- CLOCK UPDATE ---
        if (clockMode && !displayOff) {
            showClockNow();
        }

        // Helligkeit
        if (displayOff) {
            display.displaySetBrightness(0);
        } else if (nightMode) {
            display.displaySetBrightness(25);
        } else if (cfgBrightness >= 0) {
            display.displaySetBrightness(cfgBrightness);
        } else {
            #if BRIGHTNESS_FIXED >= 0
                display.displaySetBrightness(BRIGHTNESS_FIXED);
            #else
                sensorValue = analogRead(A0);
                sensorValue = map(sensorValue, 0, 4095, 12, 255);
                display.displaySetBrightness(sensorValue);
            #endif
        }

        // --- 3. DEPARTURE DISPLAY ---
        if (newDeptData && !displayOff && !clockMode) {
            newDeptData = false;
            if (xSemaphoreTake(deptMutex, 0) == pdTRUE) {
                if (deptLastCode == 0) display.printLines(api->doc.as<JsonArray>());
                else display.printError("API Error: " + String(deptLastCode) + "\n" + String(deptErrBuf) + "\nheap:" + String(ESP.getMaxAllocHeap() / 1024) + "K");
                xSemaphoreGive(deptMutex);
            }
        }
    }
}

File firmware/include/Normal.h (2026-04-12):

#ifndef CONFIG_H
#define CONFIG_H

#define TIME_SERVER "0.ch.pool.ntp.org"
#define AP_NAME "vbz-anzeige"
#define AP_PASSWORD "123456"

// Api
#define OPEN_DATA_API_KEY "eyJvcmciOiI2NDA2NTFhNTIyZmEwNTAwMDEyOWJiZTEiLCJpZCI6ImQ0Njk3NmUyNmUwYTQ5ZTM4NTZiNjk4ZWVhYjY0MzAzIiwiaCI6Im11cm11cjEyOCJ9"
#define OPEN_DATA_URL "https://api.opentransportdata.swiss/ojp20"
#define OPEN_DATA_STATION "8591324" // Zürich Röslistrasse
#define OPEN_DATA_RESULTS "5"
#define OPEN_DATA_DIRECTION "A" // H = Outward, R = Return, A = All

// Display (angepasst für ESP32-S3 DevKit / S3-N16R8)
// (nur dieser Teil wurde geändert)

// RGB Daten
#define R1_PIN  4
#define G1_PIN  5
#define B1_PIN  6
#define R2_PIN  7
#define G2_PIN  15
#define B2_PIN  16

// Adress-Leitungen
#define A_PIN   17
#define B_PIN   18
#define C_PIN   8
#define D_PIN   9
#define E_PIN   10  // nötig bei 64x64 (1/32 scan)

// Steuerung
#define LAT_PIN 11
#define OE_PIN  12
#define CLK_PIN 13

#define PANEL_RES_X 128 // Number of pixels wide of each INDIVIDUAL panel module.
#define PANEL_RES_Y 64  // Number of pixels tall of each INDIVIDUAL panel module.
#define PANEL_CHAIN 3   // Total number of panels chained one to another

#endif

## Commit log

2026-04-12 Restructure repo, rewrite README, update license
    - Rename vbz-fahrgastinformation-master/ to firmware/
    - Add root README with full documentation and correct wiring table
    - Add Artur Melnikov to LICENSE
    - Add hardware/3d/, hardware/pcb/, photos/ folders
    [Normal.h, main.cpp]
2026-04-13 Add full BOM to hardware section
2026-04-13 Update README photos — Nice.png as hero, remove back shot
2026-04-13 Add laser-cut DXF files for acrylic front plate and MDF base plate
    [AcrylicFrontPlate.dxf, MDF BasePlate .dxf]
2026-04-13 Add PCB files — schematics, Gerbers, BOM, STEP, assembly drawing
    [BOM_[No Variations].csv, STEP_[No Variations] for PCB1.PcbDoc.step]
2026-04-13 Redesign README — badges, TOC, gallery grid, cleaner layout
2026-04-13 Add texture generator, PCB render, troubleshooting section; ignore generated textures

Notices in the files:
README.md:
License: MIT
